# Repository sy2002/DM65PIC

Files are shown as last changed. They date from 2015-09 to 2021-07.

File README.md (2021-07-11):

# Firmware for the DM65PIC
## MEGA65 Computer
DM65PIC_PCBs

MEGA65 is an open-source new and open C65-like computer.
All hardware designs and all software are open-source (LGPL).
Please visit www.mega65.org to learn more about it.

## Quickstart

Click here: [How to flash the firmware on the DM65PIC](bin/README.md)

## DM65PIC Peripheral Interface Controller
The DM65PIC is the peripheral interface controller for the MEGA65 computer.
It is based on the [STM32F4 microcontroller](http://www.st.com/stm32f4).

The purpose of the DM65PIC is to provide an interface to an original
Commodore 65 prototype keyboard or a standard C64 keyboard and to provide
joystick ports. Future versions will also be able to work with the MEGA65
custom keyboard and these keyboards will also be able to be used as standard
USB HID devices e.g. while using emulators. Additionally we will implement the
Commodore 65 user port in future versions.

Here is a foto of some prototype version of our custom PCB:

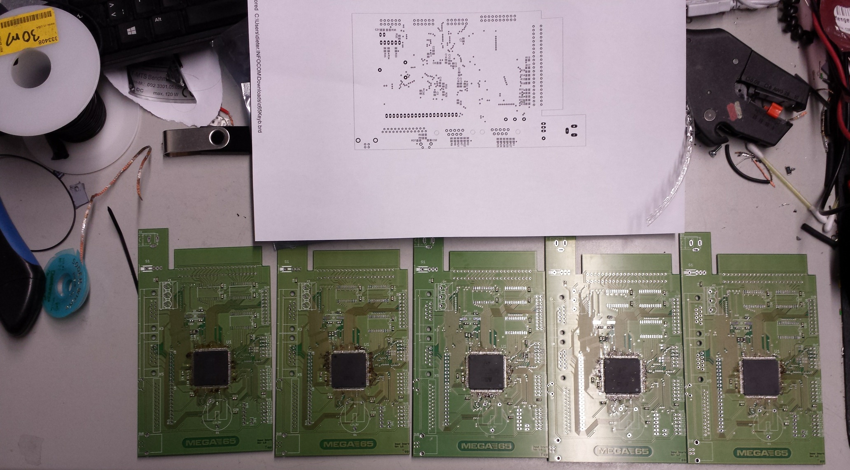
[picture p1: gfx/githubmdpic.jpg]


This GitHub repository is containing the firmware of the DM65PIC.

You can see a combination of a MEGA65 FPGA prototype (based on a Nexys 4 DDR
board), a DMPIC65 prototype and a very first work-in-progress version of the
firmware in conjuncton with a real Commodore 65 prototype keyboard in action
on YouTube: [https://youtu.be/5PpsEw80j3M](https://youtu.be/5PpsEw80j3M).

### Folder structure
```
00-STM32F4xx_STANDARD_PERIPHERAL_DRIVERS  STM32 CMSIS and standard peripheral drivers
00-STM32F429_LIBRARIES                    Tilen Majerle's STM32F4 library
01-DM65PIC                                Firmware for the DM65PIC
bin                                       Firmware binary and how-to-flash documentation
eagle                                     Hardware design for the PCB
```

The actual firmware is located within the file `main.c` in the folder
`01-DM65PIC/01-DM65PIC/User`.

### How to flash
In the folder `bin` you always find the latest binary version of the firmware
as a `.hex` file. There is also the file `bin/README.md` that explains you
how to build a cable and how to flash the DM65PIC firmware using a Windows,
OSX or Linux machine.

### How to build
We used the free version of [Keil uVision5](http://www.keil.com/uvision/).
The free version is code-size constrained (32KB), but as our compiled firmware
(including all the libs) is smaller than 32KB, the free version works fine.

After having installed the Keil IDE, just double click or open the file
`project.uvprojx` in the `01-DM65PIC` folder. As all paths are relative, you
should be able to build without further modifications.

### How the interface works
The DM65PIC is doing a matrix scan on the original Commodore 65 keyboard by
letting current flow through the columns and then find out if a key is pressed
by checking, if the current from the column arrives at a certain row. That
means, we configure all "column pins" of the STM32 microcontroller as outputs
(no pullup/pulldown resistor) and all "row pins" as inputs (pulldown
resistor).

The following diagram is the basis for the matrix scan. It is taken from
Commodore's original document
[c65manual.txt](http://www.zimmers.net/cbmpics/cbm/c65/c65manual.txt)
([permalink](https://perma.cc/E5R3-MEXA)),
chapter 2.1.2.

```

            +-----+-----+-----+-----+-----+-----+-----+-----+-----+            +-----+
            | C0  | C1  | C2  | C3  | C4  | C5  | C6  | C7  | C8  |            | GND |
            |PIN20|PIN19|PIN18|PIN17|PIN16|PIN15|PIN14|PIN13|PIN-4|            |PIN-1|
            +--+--+--+--+--+--+--+--+--+--+--+--+--+--+--+--+--+--+            +--+--+
               |     |     |     |     |     |     |     |     |                  |
               |     |     |     |     |     |     |     |     |                  |
               V     V     V     V     V     V     V     V     V                  |
+-----+     +-----+-----+-----+-----+-----+-----+-----+-----+-----+               |
| R0  |<----+ INS |  #  |  %  |  '  |  )  |  +  | œ   |  !  | NO  |               |
|PIN12|     | DEL |  3  |  5  |  7  |  9  |     |     |  1  | SCRL|               |
+-----+     +-----+-----+-----+-----+-----+-----+-----+-----+-----+               |
| R1  |<----+ RET |  W  |  R  |  Y  |  I  |  P  |  *  | <-- | TAB |               |
|PIN11|     |     |     |     |     |     |     |     |     |     |               |
+-----+     +-----+-----+-----+-----+-----+-----+-----+-----+-----+               |
| R2  |<----+ HORZ|  A  |  D  |  G  |  J  |  L  |  ]  | CTRL| ALT |               |
|PIN10|     | CRSR|     |     |     |     |     |  ;  |     |     +----------+    |
+-----+     +-----+-----+-----+-----+-----+-----+-----+-----+-----+          |    |
| R3  |<----+ F8  |  $  |  &  |  {  |  0  |  -  | CLR |  "  | HELP|          |    |
|PIN-9|     | F7  |  4  |  6  |  8  |     |     | HOM |  2  |     |          |    |
+-----+     +-----+-----+-----+-----+-----+-----+-----+-----+-----+          |    |
| R4  |<----+ F2  |  Z  |  C  |  B  |  M  |  >  |RIGHT|SPACE| F10 |          |    |
|PIN-8|     | F1  |     |     |     |     |  .  |SHIFT| BAR | F9  |          |    |
+-----+     +-----+-----+-----+-----+-----+-----+-----+-----+-----+          |    |
| R5  |<----+ F4  |  S  |  F  |  H  |  K  |  [  |  =  | C=  | F12 |          |    |
|PIN-7|     | F3  |     |     |     |     |  :  |     |     | F11 |          |    |
+-----+     +-----+-----+-----+-----+-----+-----+-----+-----+-----+          |    |
| R6  |<----+ F6  |  E  |  T  |  U  |  O  |  @  |  ã  |  Q  | F14 |          |    |
|PIN-6|     | F5  |     |     |     |     |     |  ^  |     | F13 |          |    |
+-----+     +-----+-----+-----+-----+-----+-----+-----+-----+-----+          |    |
| R7  |<----+ VERT|LEFT |  X  |  V  |  N  |  <  |  ?  | RUN | ESC +------+   |    |
|PIN-5|     | CRSR|SHIFT|     |     |     |  ,  |  /  | STOP|     +--+   |   |    |
+-----+     +--+--+--+--+-----+-----+-----+-----+--+--+-----+-----+  |   |   |    |
               |     |                             |                 |   |   |    |
               |     |                             |                 |   |   |    |
               |  +--+--+     /      (LOCKING)     |                 |   |   |    |
               |  |SHIFT+----+  +------------------------------------+   |   |    |
               |  | LOCK|                          |                     |   |    |
               |  +-----+                          |                     |   |    |
               |                             +-----+-----+               |   |    |
            +--+--+                          |           |               |   |    |
            |CRSR +------------+-------------+           +---------------+   |    |
            | UP  |        K1 PIN-21         |           |                   |    |
            +--+--+                          |   4066    |                   |    |
               |                             |  DECODER  |                   |    |
            +--+--+                          |           |                   |    |
            |CRSR +------------+-------------+           +-------------------+    |
            |LEFT |        K2 PIN-22         |           |                        |
            +-----+                          +-----------+                        |
                                                                                  |
+-----+           +-----+     /                                                   |
| NMI | <---------+RESTR+----+  +-------------------------------------------------+
|PIN-3|           |     |                                                         |
+-----+           +-----+                                                         |
                                                                                  |
                                                                                  |
+-----+           +-----+     /      (LOCKING)                                    |
| R8  | <---------+CAPS +----+  +-------------------------------------------------+
|PIN-2|           |LOCK |
+-----+           +-----+

Keyboard Notes:

1. The  64 keys under C0 through C7 occupy the same matrix position as
   in the C/64,  as does the RESTORE key.  Including SHIFT-LOCK, there
   are 66 such keys.

2. The  extended  keyboard consists of the 8 keys under the C8 output.
   Counting the CAPS-LOCK key, there are 9 new keys. The C/64 does not
   scan these keys.

3. The new CURSOR LEFT and CURSOR UP keys simulate a CURSOR plus RIGHT
   SHIFT key combination.

4. The  keyboard mechanism will be mechanically similar to that of the
   C128.
```

While scanning the matrix, the DM65PIC firmware stores the status of each
single key in an array, that is then transmitted to the MEGA65 FPGA using
the Nexys 4 DDR's General Purpose IO (GPIO) port "JB".

The protocol between the DM65PIC and the FPGA works like this: Cyclically,
128-bit are transmitted as 32 (4-bit) nibbles. Each nibble represents 4 bit
within the above-mentioned matrix. Nibble #0 represents the keys INS/DEL,
RET, HORZ/CRSR, F8/F7. Nibble #1 represents F2/F1, F4/F3, F6/F5, VERT/CRSR.
And so on. Here is the full description of the data sequence:

```
nbls #0 - #17:   keyboard bits corresponding to the 9 columns of keys (see above)
nbl #18:         joystick 1: bit0=up, bit1=down, bit2=left, bit3=right
nbl #19:         bit0=joy1 fire, bit2=capslock key status, bit3=restore key status
nbl #20:         joystick 2: bit0=up, bit1=down, bit2=left, bit3=right
nbl #21:         bit0=joy2 fire, bit3=reset momentary-action switch status
nbl #22 onwards: expansion port connector
```

The nibbles are transmitted by setting below-mentioned "bit0" .. "bit3" pins
of the "JB" port and then clocking pin "JB1". For synchronizing the
transmission, the "start of sequence" pin "JB2" is used as soon as a new
128-bit package starts.

The FPGA is also able to communicate back to the DM65PIC, i.e. for transmitting
the LED status; but this is not supported, yet in the current version of the
firmware.

Here is the pin layout for the FPGA's "JB" port:

```
JB1  = PG8:  clock; data must be valid before rising edge
JB2  = PG9:  start of sequence, set to 1 on first nibble of a new 128bit sequence
JB3  = PG10: bit0 of output data nibble
JB4  = PG11: bit1 of output data nibble
JB7  = PG12: bit2 of output data nibble
JB8  = PG13: bit3 of output data nibble
JB9  = PG14: bit 0 of input bit pair
JB10 = PG15: bit 1 of input bit pair
```

### Credits
* [Paul Gardner-Stephen](http://c65gs.blogspot.de): MEGA65 main developer
* [Deft](http://www.m-e-g-a.org/de/mega/profile): chief MEGA65 officer
* doubleflash: DM65PIC hardware design
* [sy2002](http://www.sy2002.de): DM65PIC firmware in this GitHub repository

Special thanks go to [Tilen Majerle](https://github.com/MaJerle) for
supporting sy2002 in learning how to work with the STM32 toolchain and of
course for creating the awesome [STM32F4 library](https://stm32f4-discovery.net)
that we heavily used for creating the DM65PIC firmware.

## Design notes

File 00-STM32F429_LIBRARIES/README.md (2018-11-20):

# Libraries

Each library listed here is described at
https://stm32f4-discovery.net/

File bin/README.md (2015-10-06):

How to flash the firmware on the DM65PIC
========================================

Get the latest firmware and instructions here:

https://github.com/sy2002/DM65PIC/tree/master/bin

What you need
-------------

1. You need to have a ST-LINK/V2 (or compatible) device connected to any
   USB port of your PC, Mac or Linux device.

2. You need a cable that maps the 20-pin connector of the ST-LINK device
   to the 6-pin connector on the DM65PIC board. (Depending on the type of your
   ST-LINK device, you might only need to connect 4 or 5 of the 6 pins on the
   DM65PIC.)

3. You need either the original STLINK tool, if you're using Windows or
   the Open Source tool OpenOCD, if you're using OSX or Linux.

Cables and Devices
------------------

There a lot of ST-LINK/V2 compatible devices out there. We tried the original
from ST as well as cheap Chines clones. It works, no matter what (compatible)
device you are using, as long as you have the right pin-mapping on the cable.

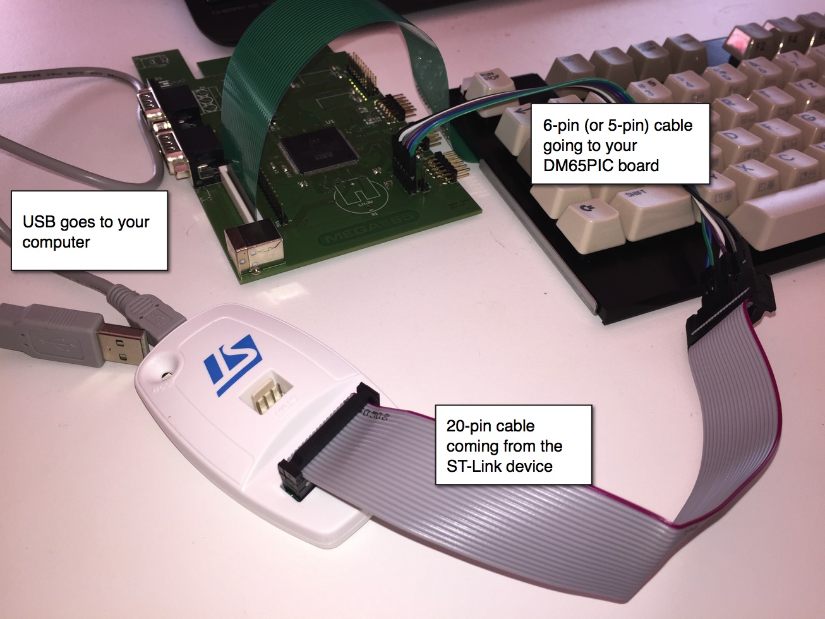
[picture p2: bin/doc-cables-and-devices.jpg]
Cables-and-Devices

   
As you can see on the image above, the programmer is connected via USB to your
host machine. Instructions for Windows, Mac and Linux of about the software
side of things are below.

Let's focus on the cable first: Most ST-LINK devices come with some kind of
a 20-pin connector. We don't need all of these 20 pins to program the DM65PIC,
but just 4 or 5 of them are really essential. Optionally, we can connect
pin 6, which then can be used to display debug- and trace-output on a console.

The original ST-LINK device needs 5 pins as it needs the +3.3 volt line. In
contrast to this, some Chinese clones do not need the +3.3 volt line, so that
4 pins are sufficient for these devices (pins 1 and 6 are omitted).

The following picture is showing you, where to find the 6-pin connector on the
DM65PIC board. You are counting the 6 pins from top to bottom:

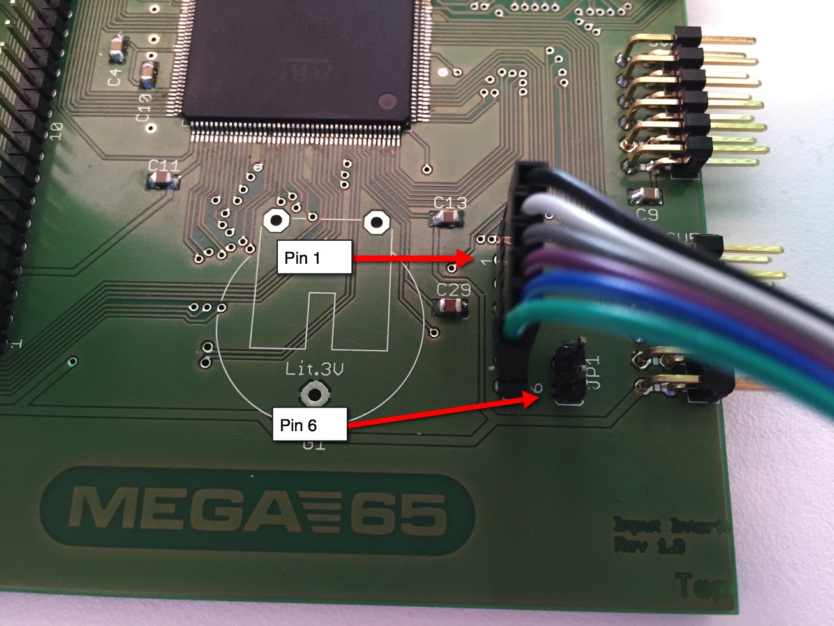
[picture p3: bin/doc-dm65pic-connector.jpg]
DM65PIC-Connector


The meaning of the 6 pins is the following:

```
1 +3.3 volt  (The programmer uses this to detect the device)
2 SWCLK      (ST Wire Bus Clock)
3 GND
4 SWDIO      (ST Input/Output)
5 NRST       (Reset Wire)
6 SWDTO      (Trace Output, this is optional and not needed for flashing)
```

To build the mapping from the 20-pin ST-LINK cable to the 6-pin DM65PIC
connector, you need standard jumper wires male-female or female-female
(depending on how your ST-LINK cable or adapter looks). Some of the ST-LINK
devices are already coming with a set of jumper wires, but you can also
easily get them on eBay or Amazon: Just enter something like
`jumper wire male female` or `breadboard cable male female` into the
search bar. It looks like this:

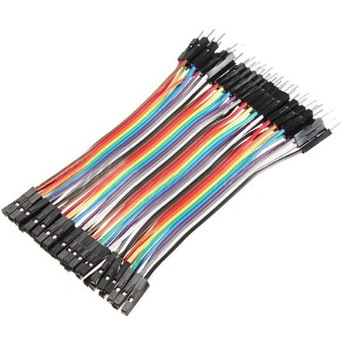
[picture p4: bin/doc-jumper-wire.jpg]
Jumper-Wire-Male-Female


"Mapping" as mentioned above now means: Make sure, that the 3.3 volt pin of
your programming device maps to the 3.3 volt pin of the DM65PIC, which is
pin 1. Make sure, that the SWCLK pin of the programming device maps to the
SWCLK pin of the DM65PIc, which is pin 2. And so on. You can find out the
mapping by having a look in the reference manual of your device.

If you are using an original device from ST or a device with compatible
connectors, then the mapping is as follows:

```
   DM65PIC       ST-LINK
      *1   --->     1
       2   --->     9
       3   --->     6
       4   --->     7
       5   --->    15
     **6   --->    13

(*)  not needed when using some Chinese clones
(**) optional connection, only used for tracing/debugging (ARM Semihosting)
```

Make sure, that you are counting the pins on the ST-LINK connector in the
right way as shown in the following image:

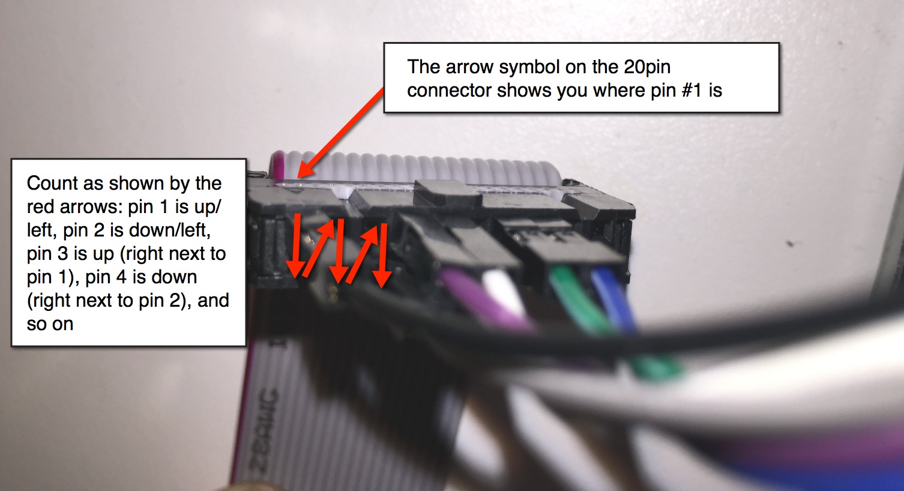
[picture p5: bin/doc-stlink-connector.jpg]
how-to-count


Now you are ready to program / flash your DM65PIC board as described in the
following sections.

Windows
-------

1. Go to www.st.com

2. Enter   STSW-LINK004   in the search box on the top right

3. Click on the first search result

4. Download, install and start the software

5. Choose "Connect" from the "Target" menu. If this is not working,
   then your STLINK-to-DM65PIC cable is wrong and/or DM65PIC is not powered.

6. The "Connect" takes about 5 seconds

7. Choose "Program & Verify" from the "Target" menu

8. Choose the `dm65pic-firmware-rev3.hex` file

9. Select "Verify after programming" and make sure that "Reset after
   programming" is checked.

10. Press "Start".

The firmware is now persistently flashed and will start as soon
as the DM65PIC is powered on.

Mac OSX or Linux
----------------

1. Get the tool OpenOCD from here http://openocd.org

2. For OSX users: If you use homebrew (recommended! http://brew.sh) then
   installing OpenOCD is very easy. Just open a terminal and enter:

   `brew install openocd`

3. Copy the file `dm65pic.cfg` from this repository to some folder on your
   computer, open a terminal and go to that folder where you copied
   `dm65pic.cfg`.

4. Enter:

   `openocd --file dm65pic.cfg`

   If any error occurs, then your cable STLINK-to-DM65PIC is wrong and/or
   DM65PIC is not powered.

5. Executing (4) creates a local telnet server on port 4444, so open another
   terminal window and enter

   `telnet localhost 4444`

6. Enter

   `halt`

7. Enter

   `flash write_image erase <fullpath-to-the-hex-file>`

   In the <fullpath-to-the-hex-file> no things like "~" are allowed.
   Use really the full path starting from the root folder.

8. If an error occurs,  enter:

    ```
    halt
    reset
    halt
    ```

9. And then try (7) again.

10. If it says something like "wrote xyz bytes from file abc" then enter

   `reset`

   (reset starts the firmware)

11. Enter:

    `exit`

12. You can now close all terminal windows, including the OpenOCD server

The firmware is now persistently flashed and will start as soon
as the DM65PIC is powered on.

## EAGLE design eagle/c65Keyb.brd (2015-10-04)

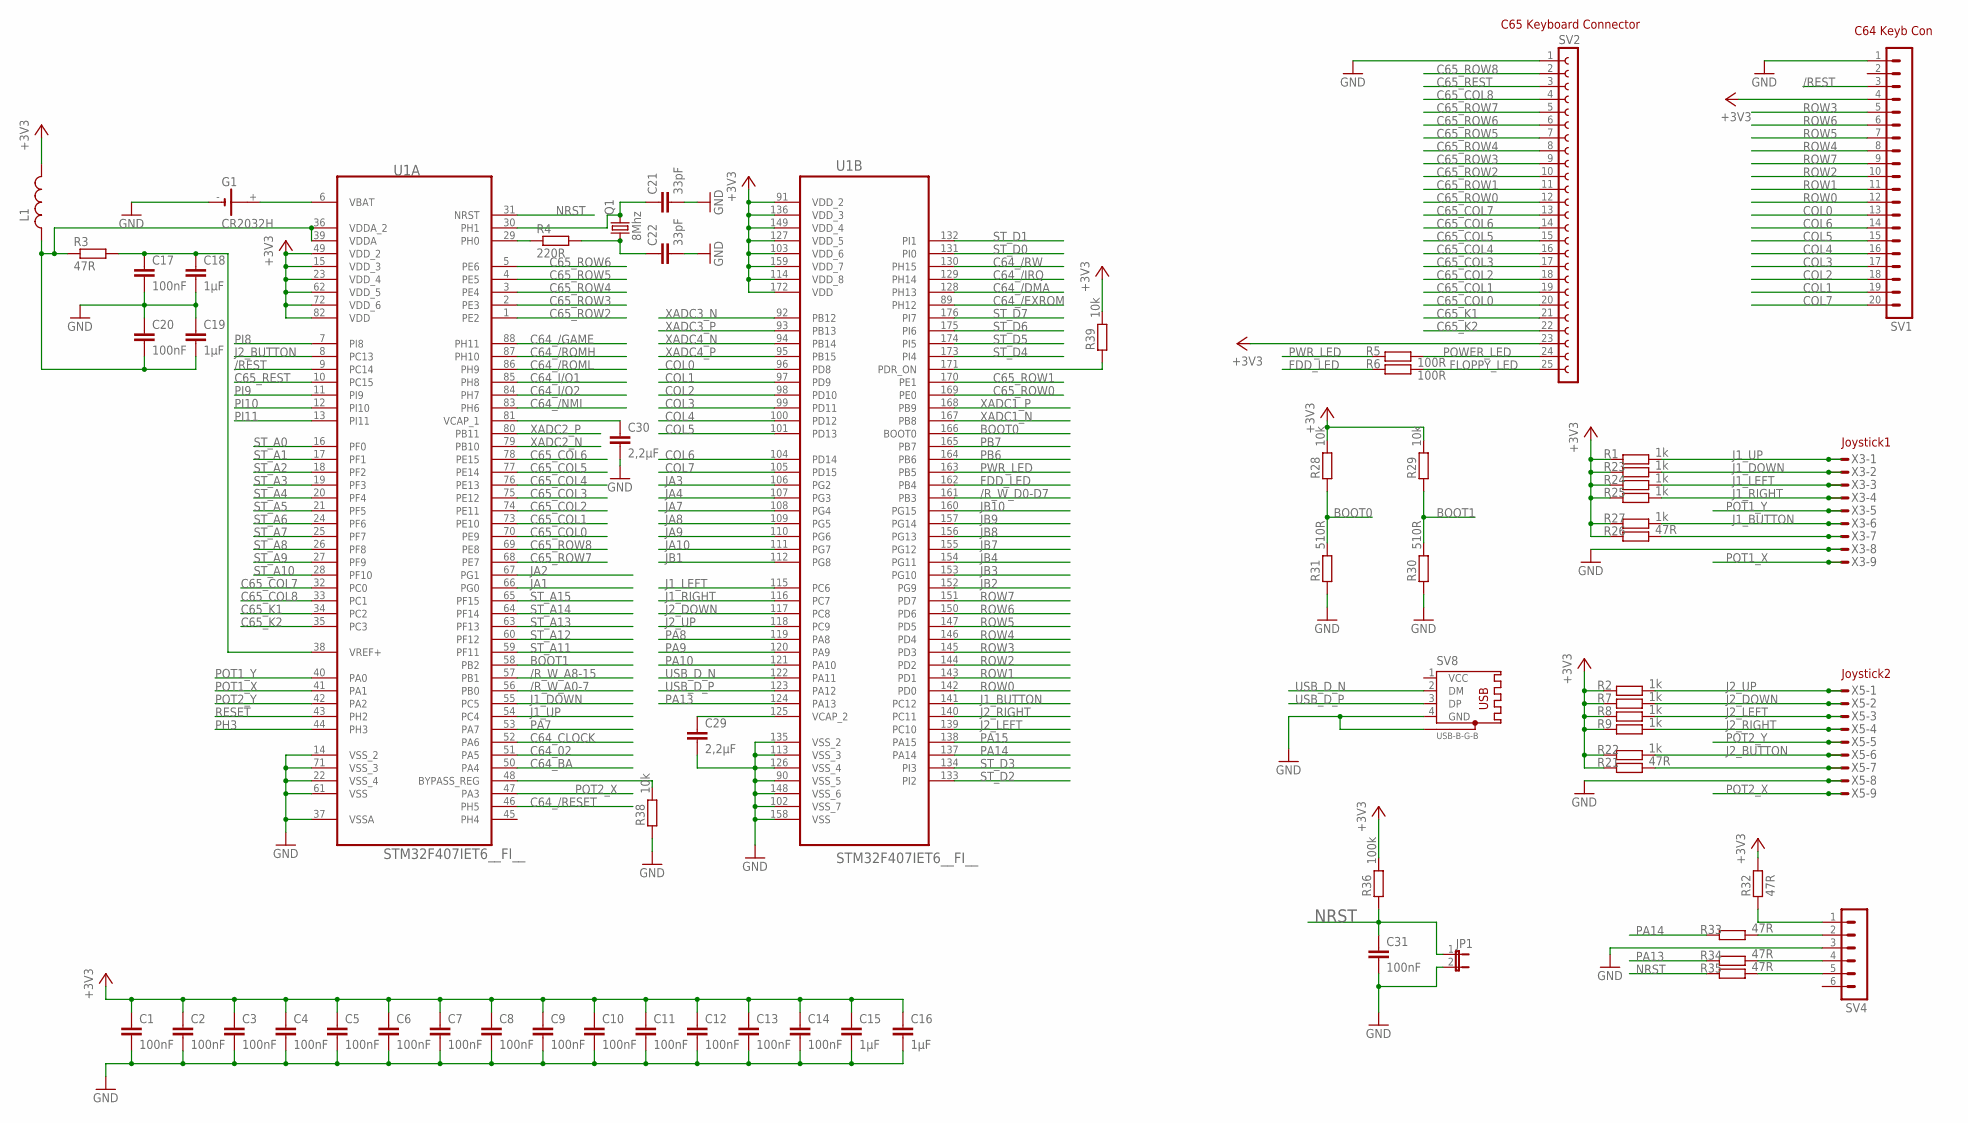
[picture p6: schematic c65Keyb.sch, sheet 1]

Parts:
C1, C2, C3, C4, C5, C6, C7, C8, C9, C10, C11, C12, C13, C14, C17, C20, C31: 100nF; C0805
C15, C16, C18, C19: 1µF; C0805
C21, C22: 33pF; C0805
C29, C30: 2,2µF; C0805
G1: CR2032H
JP1: JP1E; JP1
L1: L-0805A; SMD0805-ALT
Q1: 8Mhz; HC49UP
R1, R2, R7, R8, R9, R22, R23, R24, R25, R27: 1k; R0805
R3, R21, R26, R32, R33, R34, R35: 47R; R0805
R4: 220R; R0805
R5, R6: 100R; R0805
R28, R29, R38, R39: 10k; R0805
R30, R31: 510R; R0805
R36: 100k; R0805
SV1: MA20-1
SV2: C65_MOLEX_KEYB
SV4: MA06-1
SV8: USB-B-G-B; USB-B-THG-01
U1: STM32F407IET6__FI__; QFP176
X3, X5: M09-182S; 182-009-MALE

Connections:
+3V3: C1.1, C2.1, C3.1, C4.1, C5.1, C6.1, C7.1, C8.1, C9.1, C10.1, C11.1, C12.1, C13.1, C14.1, C15.1, C16.1, L1.2, R1.1, R2.1, R7.1, R8.1, R9.1, R21.1, R22.1, R23.1, R24.1, R25.1, R26.1, R27.1, R28.2, R29.2, R32.2, R36.2, R39.2, SV1.4, SV2.23, U1.15 (VDD_3), U1.23 (VDD_4), U1.49 (VDD_2), U1.62 (VDD_5), U1.72 (VDD_6), U1.82 (VDD), U1.91 (VDD_2), U1.103 (VDD_6), U1.114 (VDD_8), U1.127 (VDD_5), U1.136 (VDD_3), U1.149 (VDD_4), U1.159 (VDD_7), U1.172 (VDD); also elsewhere on the board
/REST: SV1.3, U1.9 (PC14)
/R_W_A0-7: U1.56 (PB0); also elsewhere on the board
/R_W_A8-15: U1.57 (PB1); also elsewhere on the board
/R_W_D0-D7: U1.161 (PB3); also elsewhere on the board
BOOT0: R28.1, R31.2, U1.166 (BOOT0)
BOOT1: R29.1, R30.2, U1.58 (PB2)
C64_02: U1.51 (PA5); also elsewhere on the board
C64_/DMA: U1.128 (PH13); also elsewhere on the board
C64_/EXROM: U1.89 (PH12); also elsewhere on the board
C64_/GAME: U1.88 (PH11); also elsewhere on the board
C64_/IRQ: U1.129 (PH14); also elsewhere on the board
C64_/NMI: U1.83 (PH6); also elsewhere on the board
C64_/RESET: U1.46 (PH5); also elsewhere on the board
C64_/ROMH: U1.87 (PH10); also elsewhere on the board
C64_/ROML: U1.86 (PH9); also elsewhere on the board
C64_/RW: U1.130 (PH15); also elsewhere on the board
C64_BA: U1.50 (PA4); also elsewhere on the board
C64_CLOCK: U1.52 (PA6); also elsewhere on the board
C64_I/O1: U1.85 (PH8); also elsewhere on the board
C64_I/O2: U1.84 (PH7); also elsewhere on the board
C65_COL0: SV2.20, U1.70 (PE9)
C65_COL1: SV2.19, U1.73 (PE10)
C65_COL2: SV2.18, U1.74 (PE11)
C65_COL3: SV2.17, U1.75 (PE12)
C65_COL4: SV2.16, U1.76 (PE13)
C65_COL5: SV2.15, U1.77 (PE14)
C65_COL6: SV2.14, U1.78 (PE15)
C65_COL7: SV2.13, U1.32 (PC0)
C65_COL8: SV2.4, U1.33 (PC1)
C65_K1: SV2.21, U1.34 (PC2)
C65_K2: SV2.22, U1.35 (PC3)
C65_REST: SV2.3, U1.10 (PC15)
C65_ROW0: SV2.12, U1.169 (PE0)
C65_ROW1: SV2.11, U1.170 (PE1)
C65_ROW2: SV2.10, U1.1 (PE2)
C65_ROW3: SV2.9, U1.2 (PE3)
C65_ROW4: SV2.8, U1.3 (PE4)
C65_ROW5: SV2.7, U1.4 (PE5)
C65_ROW6: SV2.6, U1.5 (PE6)
C65_ROW7: SV2.5, U1.68 (PE7)
C65_ROW8: SV2.2, U1.69 (PE8)
COL0: SV1.13, U1.96 (PD8)
COL1: SV1.19, U1.97 (PD9)
COL2: SV1.18, U1.98 (PD10)
COL3: SV1.17, U1.99 (PD11)
COL4: SV1.16, U1.100 (PD12)
COL5: SV1.15, U1.101 (PD13)
COL6: SV1.14, U1.104 (PD14)
COL7: SV1.20, U1.105 (PD15)
FDD_LED: R6.1, U1.162 (PB4)
FLOPPY_LED: R6.2, SV2.25
GND: C1.2, C2.2, C3.2, C4.2, C5.2, C6.2, C7.2, C8.2, C9.2, C10.2, C11.2, C12.2, C13.2, C14.2, C15.2, C16.2, C17.2, C18.2, C19.1, C20.1, C21.2, C22.2, C29.2, C30.2, C31.2, G1.-, JP1.2, R30.1, R31.1, R38.1, SV1.1, SV2.1, SV4.3, SV8.4 (GND), SV8.G1, U1.14 (VSS_2), U1.22 (VSS_4), U1.37 (VSSA), U1.61 (VSS), U1.71 (VSS_3), U1.90 (VSS_5), U1.102 (VSS_7), U1.113 (VSS_3), U1.126 (VSS_4), U1.135 (VSS_2), U1.148 (VSS_6), U1.158 (VSS), X3.8, X5.8; also elsewhere on the board
J1_BUTTON: R27.2, U1.141 (PC12), X3.6
J1_DOWN: R23.2, U1.55 (PC5), X3.2
J1_LEFT: R24.2, U1.115 (PC6), X3.3
J1_RIGHT: R25.2, U1.116 (PC7), X3.4
J1_UP: R1.2, U1.54 (PC4), X3.1
J2_BUTTON: R22.2, U1.8 (PC13), X5.6
J2_DOWN: R7.2, U1.117 (PC8), X5.2
J2_LEFT: R8.2, U1.139 (PC10), X5.3
J2_RIGHT: R9.2, U1.140 (PC11), X5.4
J2_UP: R2.2, U1.118 (PC9), X5.1
JA1: U1.66 (PG0); also elsewhere on the board
JA2: U1.67 (PG1); also elsewhere on the board
JA3: U1.106 (PG2); also elsewhere on the board
JA4: U1.107 (PG3); also elsewhere on the board
JA7: U1.108 (PG4); also elsewhere on the board
JA8: U1.109 (PG5); also elsewhere on the board
JA9: U1.110 (PG6); also elsewhere on the board
JA10: U1.111 (PG7); also elsewhere on the board
JB1: U1.112 (PG8); also elsewhere on the board
JB2: U1.152 (PG9); also elsewhere on the board
JB3: U1.153 (PG10); also elsewhere on the board
JB4: U1.154 (PG11); also elsewhere on the board
JB7: U1.155 (PG12); also elsewhere on the board
JB8: U1.156 (PG13); also elsewhere on the board
JB9: U1.157 (PG14); also elsewhere on the board
JB10: U1.160 (PG15); also elsewhere on the board
unnamed: G1.+, U1.6 (VBAT)
unnamed: R4.1, U1.29 (PH0)
unnamed: C17.1, C18.1, R3.2, U1.38 (VREF+)
unnamed: R21.2, X5.7
unnamed: C30.1, U1.81 (VCAP_1)
unnamed: C29.1, U1.125 (VCAP_2)
unnamed: R32.1, SV4.1
unnamed: R33.2, SV4.2
unnamed: R34.2, SV4.4
unnamed: R26.2, X3.7
unnamed: R35.2, SV4.5
unnamed: R38.2, U1.48 (BYPASS_REG)
unnamed: C21.1, Q1.2, U1.30 (PH1)
unnamed: C22.1, Q1.1, R4.2
unnamed: R39.1, U1.171 (PDR_ON)
unnamed: C19.2, C20.2, L1.1, R3.1, U1.36 (VDDA_2), U1.39 (VDDA)
NRST: C31.1, JP1.1, R35.1, R36.1, U1.31 (NRST)
PA7: U1.53 (PA7); also elsewhere on the board
PA8: U1.119 (PA8); also elsewhere on the board
PA9: U1.120 (PA9); also elsewhere on the board
PA10: U1.121 (PA10); also elsewhere on the board
PA13: R34.1, U1.124 (PA13)
PA14: R33.1, U1.137 (PA14)
PA15: U1.138 (PA15); also elsewhere on the board
PB6: U1.164 (PB6); also elsewhere on the board
PB7: U1.165 (PB7); also elsewhere on the board
PH3: U1.44 (PH3); also elsewhere on the board
PI8: U1.7 (PI8); also elsewhere on the board
PI9: U1.11 (PI9); also elsewhere on the board
PI10: U1.12 (PI10); also elsewhere on the board
PI11: U1.13 (PI11); also elsewhere on the board
POT1_X: U1.41 (PA1), X3.9
POT1_Y: U1.40 (PA0), X3.5
POT2_X: U1.47 (PA3), X5.9
POT2_Y: U1.42 (PA2), X5.5
POWER_LED: R5.2, SV2.24
PWR_LED: R5.1, U1.163 (PB5)
RESET: U1.43 (PH2); also elsewhere on the board
ROW0: SV1.12, U1.142 (PD0)
ROW1: SV1.11, U1.143 (PD1)
ROW2: SV1.10, U1.144 (PD2)
ROW3: SV1.5, U1.145 (PD3)
ROW4: SV1.8, U1.146 (PD4)
ROW5: SV1.7, U1.147 (PD5)
ROW6: SV1.6, U1.150 (PD6)
ROW7: SV1.9, U1.151 (PD7)
ST_A0: U1.16 (PF0); also elsewhere on the board
ST_A1: U1.17 (PF1); also elsewhere on the board
ST_A2: U1.18 (PF2); also elsewhere on the board
ST_A3: U1.19 (PF3); also elsewhere on the board
ST_A4: U1.20 (PF4); also elsewhere on the board
ST_A5: U1.21 (PF5); also elsewhere on the board
ST_A6: U1.24 (PF6); also elsewhere on the board
ST_A7: U1.25 (PF7); also elsewhere on the board
ST_A8: U1.26 (PF8); also elsewhere on the board
ST_A9: U1.27 (PF9); also elsewhere on the board
ST_A10: U1.28 (PF10); also elsewhere on the board
ST_A11: U1.59 (PF11); also elsewhere on the board
ST_A12: U1.60 (PF12); also elsewhere on the board
ST_A13: U1.63 (PF13); also elsewhere on the board
ST_A14: U1.64 (PF14); also elsewhere on the board
ST_A15: U1.65 (PF15); also elsewhere on the board
ST_D0: U1.131 (PI0); also elsewhere on the board
ST_D1: U1.132 (PI1); also elsewhere on the board
ST_D2: U1.133 (PI2); also elsewhere on the board
ST_D3: U1.134 (PI3); also elsewhere on the board
ST_D4: U1.173 (PI4); also elsewhere on the board
ST_D5: U1.174 (PI5); also elsewhere on the board
ST_D6: U1.175 (PI6); also elsewhere on the board
ST_D7: U1.176 (PI7); also elsewhere on the board
USB_D_N: SV8.2 (DM), U1.122 (PA11)
USB_D_P: SV8.3 (DP), U1.123 (PA12)
XADC1_N: U1.167 (PB8); also elsewhere on the board
XADC1_P: U1.168 (PB9); also elsewhere on the board
XADC2_N: U1.79 (PB10); also elsewhere on the board
XADC2_P: U1.80 (PB11); also elsewhere on the board
XADC3_N: U1.92 (PB12); also elsewhere on the board
XADC3_P: U1.93 (PB13); also elsewhere on the board
XADC4_N: U1.94 (PB14); also elsewhere on the board
XADC4_P: U1.95 (PB15); also elsewhere on the board

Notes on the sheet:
C64 Keyb Con
Joystick1
Joystick2
C65 Keyboard Connector

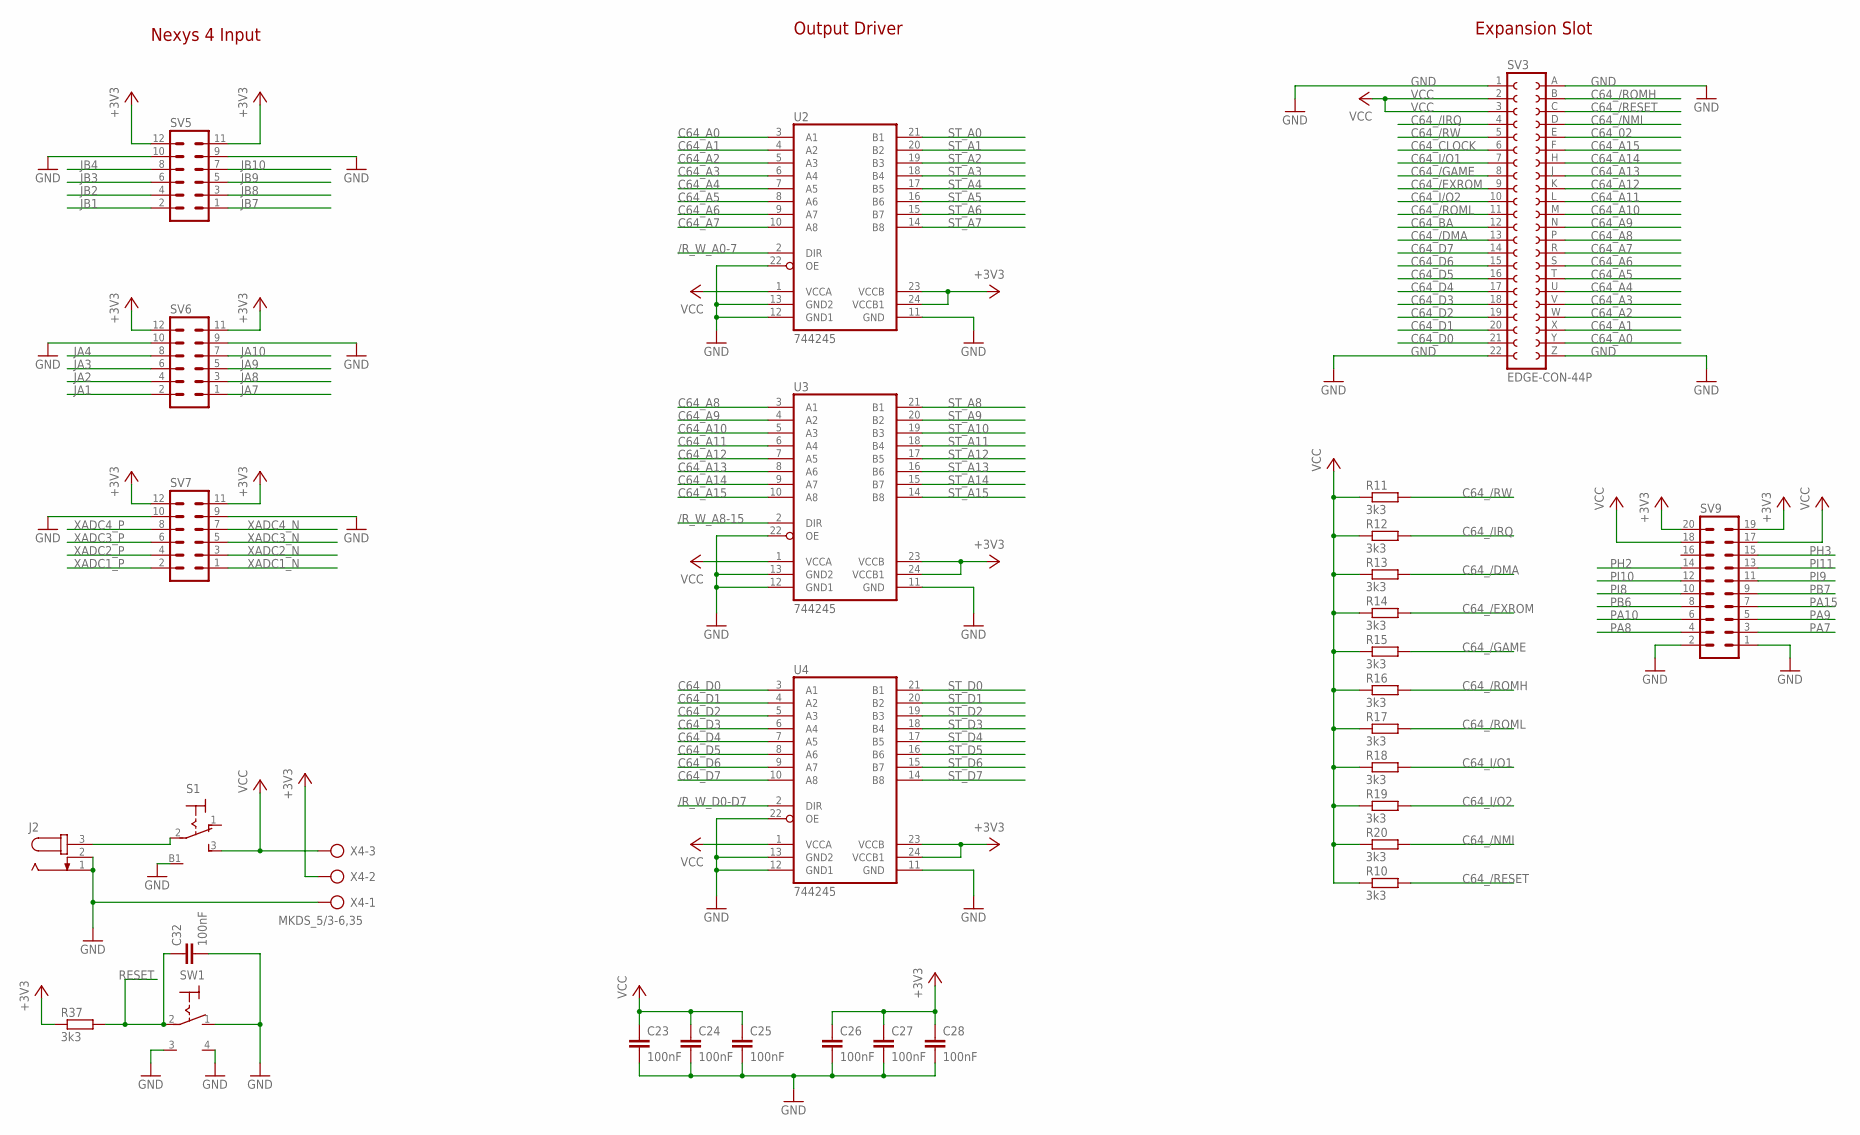
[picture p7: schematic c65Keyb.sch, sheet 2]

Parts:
C23, C24, C25, C26, C27, C28, C32: 100nF; C0805
J2: JACK-PLUG1; SPC4078
R10, R11, R12, R13, R14, R15, R16, R17, R18, R19, R20, R37: 3k3; R0805
S1: LPV-1
SV3: EDGE-CON-44P; EDGE-CON-44
SV5, SV6, SV7: MA06-2W
SV9: MA10-2
SW1: TASTER; MICRO_SWITCH
U2, U3, U4: 744245; SO24L
X4: MKDS_5/3-6,35; MKDS_5/3-635

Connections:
+3V3: C26.1, C27.1, C28.1, R37.1, SV5.11, SV5.12, SV6.11, SV6.12, SV7.11, SV7.12, SV9.19, SV9.20, U2.23 (VCCB), U2.24 (VCCB1), U3.23 (VCCB), U3.24 (VCCB1), U4.23 (VCCB), U4.24 (VCCB1), X4.2; also elsewhere on the board
/R_W_A0-7: U2.2 (DIR); also elsewhere on the board
/R_W_A8-15: U3.2 (DIR); also elsewhere on the board
/R_W_D0-D7: U4.2 (DIR); also elsewhere on the board
C64_02: SV3.E; also elsewhere on the board
C64_/DMA: R13.2, SV3.13; also elsewhere on the board
C64_/EXROM: R14.2, SV3.9; also elsewhere on the board
C64_/GAME: R15.2, SV3.8; also elsewhere on the board
C64_/IRQ: R12.2, SV3.4; also elsewhere on the board
C64_/NMI: R20.2, SV3.D; also elsewhere on the board
C64_/RESET: R10.2, SV3.C; also elsewhere on the board
C64_/ROMH: R16.2, SV3.B; also elsewhere on the board
C64_/ROML: R17.2, SV3.11; also elsewhere on the board
C64_/RW: R11.2, SV3.5; also elsewhere on the board
C64_A0: SV3.Y, U2.3 (A1)
C64_A1: SV3.X, U2.4 (A2)
C64_A2: SV3.W, U2.5 (A3)
C64_A3: SV3.V, U2.6 (A4)
C64_A4: SV3.U, U2.7 (A5)
C64_A5: SV3.T, U2.8 (A6)
C64_A6: SV3.S, U2.9 (A7)
C64_A7: SV3.R, U2.10 (A8)
C64_A8: SV3.P, U3.3 (A1)
C64_A9: SV3.N, U3.4 (A2)
C64_A10: SV3.M, U3.5 (A3)
C64_A11: SV3.L, U3.6 (A4)
C64_A12: SV3.K, U3.7 (A5)
C64_A13: SV3.J, U3.8 (A6)
C64_A14: SV3.H, U3.9 (A7)
C64_A15: SV3.F, U3.10 (A8)
C64_BA: SV3.12; also elsewhere on the board
C64_CLOCK: SV3.6; also elsewhere on the board
C64_D0: SV3.21, U4.3 (A1)
C64_D1: SV3.20, U4.4 (A2)
C64_D2: SV3.19, U4.5 (A3)
C64_D3: SV3.18, U4.6 (A4)
C64_D4: SV3.17, U4.7 (A5)
C64_D5: SV3.16, U4.8 (A6)
C64_D6: SV3.15, U4.9 (A7)
C64_D7: SV3.14, U4.10 (A8)
C64_I/O1: R18.2, SV3.7; also elsewhere on the board
C64_I/O2: R19.2, SV3.10; also elsewhere on the board
GND: C23.2, C24.2, C25.2, C26.2, C27.2, C28.2, C32.2, J2.1, J2.2, S1.B1 (B), SV3.1, SV3.22, SV3.A, SV3.Z, SV5.9, SV5.10, SV6.9, SV6.10, SV7.9, SV7.10, SV9.1, SV9.2, SW1.1 (O), SW1.3 (B), SW1.4 (B1), U2.11 (GND), U2.12 (GND1), U2.13 (GND2), U2.22 (OE), U3.11 (GND), U3.12 (GND1), U3.13 (GND2), U3.22 (OE), U4.11 (GND), U4.12 (GND1), U4.13 (GND2), U4.22 (OE), X4.1; also elsewhere on the board
JA1: SV6.2; also elsewhere on the board
JA2: SV6.4; also elsewhere on the board
JA3: SV6.6; also elsewhere on the board
JA4: SV6.8; also elsewhere on the board
JA7: SV6.1; also elsewhere on the board
JA8: SV6.3; also elsewhere on the board
JA9: SV6.5; also elsewhere on the board
JA10: SV6.7; also elsewhere on the board
JB1: SV5.2; also elsewhere on the board
JB2: SV5.4; also elsewhere on the board
JB3: SV5.6; also elsewhere on the board
JB4: SV5.8; also elsewhere on the board
JB7: SV5.1; also elsewhere on the board
JB8: SV5.3; also elsewhere on the board
JB9: SV5.5; also elsewhere on the board
JB10: SV5.7; also elsewhere on the board
unnamed: J2.3, S1.2
PA7: SV9.3; also elsewhere on the board
PA8: SV9.4; also elsewhere on the board
PA9: SV9.5; also elsewhere on the board
PA10: SV9.6; also elsewhere on the board
PA15: SV9.7; also elsewhere on the board
PB6: SV9.8; also elsewhere on the board
PB7: SV9.9; also elsewhere on the board
PH2: SV9.14
PH3: SV9.15; also elsewhere on the board
PI8: SV9.10; also elsewhere on the board
PI9: SV9.11; also elsewhere on the board
PI10: SV9.12; also elsewhere on the board
PI11: SV9.13; also elsewhere on the board
RESET: C32.1, R37.2, SW1.2; also elsewhere on the board
ST_A0: U2.21 (B1); also elsewhere on the board
ST_A1: U2.20 (B2); also elsewhere on the board
ST_A2: U2.19 (B3); also elsewhere on the board
ST_A3: U2.18 (B4); also elsewhere on the board
ST_A4: U2.17 (B5); also elsewhere on the board
ST_A5: U2.16 (B6); also elsewhere on the board
ST_A6: U2.15 (B7); also elsewhere on the board
ST_A7: U2.14 (B8); also elsewhere on the board
ST_A8: U3.21 (B1); also elsewhere on the board
ST_A9: U3.20 (B2); also elsewhere on the board
ST_A10: U3.19 (B3); also elsewhere on the board
ST_A11: U3.18 (B4); also elsewhere on the board
ST_A12: U3.17 (B5); also elsewhere on the board
ST_A13: U3.16 (B6); also elsewhere on the board
ST_A14: U3.15 (B7); also elsewhere on the board
ST_A15: U3.14 (B8); also elsewhere on the board
ST_D0: U4.21 (B1); also elsewhere on the board
ST_D1: U4.20 (B2); also elsewhere on the board
ST_D2: U4.19 (B3); also elsewhere on the board
ST_D3: U4.18 (B4); also elsewhere on the board
ST_D4: U4.17 (B5); also elsewhere on the board
ST_D5: U4.16 (B6); also elsewhere on the board
ST_D6: U4.15 (B7); also elsewhere on the board
ST_D7: U4.14 (B8); also elsewhere on the board
VCC: C23.1, C24.1, C25.1, R10.1, R11.1, R12.1, R13.1, R14.1, R15.1, R16.1, R17.1, R18.1, R19.1, R20.1, S1.3 (S), SV3.2, SV3.3, SV9.17, SV9.18, U2.1 (VCCA), U3.1 (VCCA), U4.1 (VCCA), X4.3
XADC1_N: SV7.1; also elsewhere on the board
XADC1_P: SV7.2; also elsewhere on the board
XADC2_N: SV7.3; also elsewhere on the board
XADC2_P: SV7.4; also elsewhere on the board
XADC3_N: SV7.5; also elsewhere on the board
XADC3_P: SV7.6; also elsewhere on the board
XADC4_N: SV7.7; also elsewhere on the board
XADC4_P: SV7.8; also elsewhere on the board

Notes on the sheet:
Expansion Slot
Output Driver
Nexys 4 Input

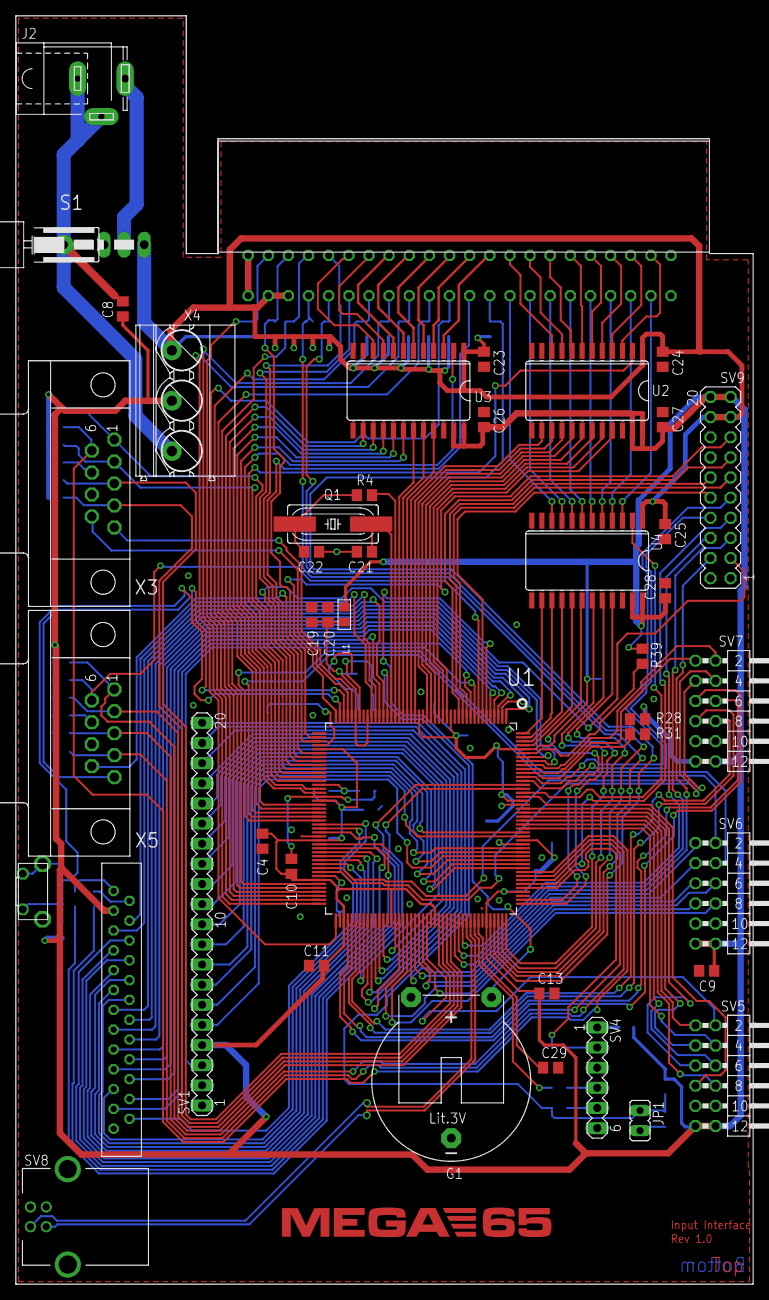
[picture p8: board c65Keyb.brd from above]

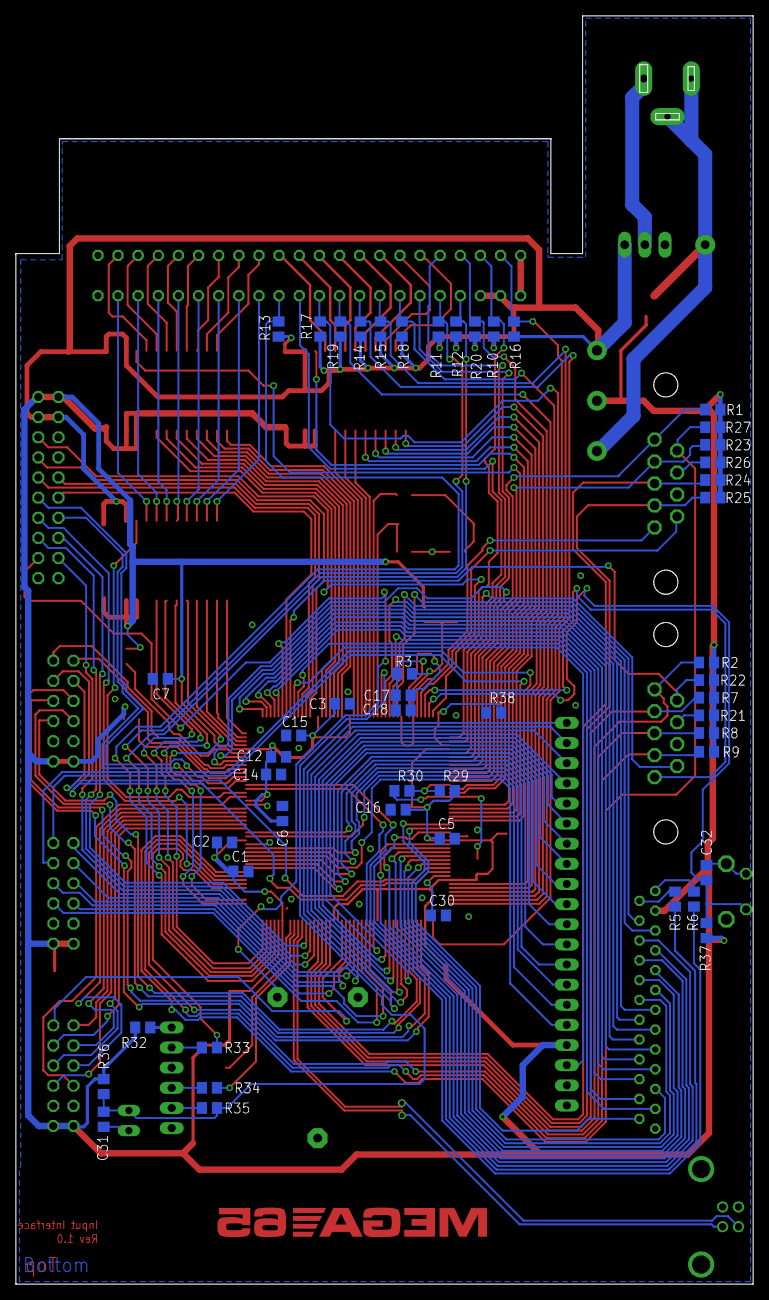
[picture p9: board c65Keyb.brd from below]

Board: 2 copper layers, 93.0 x 160.0 mm, 94 parts (50 on the bottom side), 185 nets.

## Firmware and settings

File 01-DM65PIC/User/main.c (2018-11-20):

/*
 *  FIRMWARE FOR DM65PIC (Dieter's MEGA65 Peripheral Interface Controller)
 *
 *  Keyboard, Joystick and Expansion Port interface for the MEGA65
 *  running on a Nexys 4 DDR FPGA
 * 
 *  done in September 2015 by sy2002 (http://www.sy2002.de)
 *  using Tilen Majerle's STM32F4 libraries (http://stm32f4-discovery.com)
 */

/* Include core modules */
#include "stm32f4xx.h"

/* Include STM32F4 libraries */
#include "defines.h"
#include "tm_stm32f4_swo.h"
#include "tm_stm32f4_gpio.h"
#include "tm_stm32f4_delay.h"

int main(void)
{
    /* complete state of the keyboard split into nibbles according to the FPGA transfer protocol */
    unsigned char nibbles[32] =
    {
        0x00,
        0x00,
        0x00,
        0x00,
        0x00,
        0x00,
        0x00,
        0x00,
        0x00,
        0x00,
        0x00,
        0x00,
        0x00,
        0x00,
        0x00,
        0x00,
        0x00,
        0x00,
        0x00,
        0x00,
        0x00,
        0x00,
        0x00,
        0x00,
        0x00,
        0x00,
        0x00,
        0x00,
        0x00,
        0x00,
        0x00,
        0x00       
    };
    
    
    /* map the pins of the DM65PIC to the columns and rows of the C65 and C64 keyboard
       a very good source of information is chapter 2.1.2 in the following document:

       http://www.zimmers.net/cbmpics/cbm/c65/c65manual.txt 
       
       or use this permalink

       https://perma.cc/E5R3-MEXA
    */
    
    struct GPIO_Mapping
    {
        GPIO_TypeDef* GPIOx;    /* STM32 GPIO port */
        uint16_t GPIO_Pin;      /* pin within the specified GPIO port */
    };
    
    const char Size_ColMapping_C65 = 9;
    struct GPIO_Mapping Columns_C65[Size_ColMapping_C65] =
    {
        GPIOE, GPIO_Pin_9,      /* C0 */
        GPIOE, GPIO_Pin_10,     /* C1 */
        GPIOE, GPIO_Pin_11,     /* C2 */
        GPIOE, GPIO_Pin_12,     /* C3 */
        GPIOE, GPIO_Pin_13,     /* C4 */
        GPIOE, GPIO_Pin_14,     /* C5 */
        GPIOE, GPIO_Pin_15,     /* C6 */
        GPIOC, GPIO_Pin_0,      /* C7 */
        GPIOC, GPIO_Pin_1       /* C8 */
    };
        
    const char Size_RowMapping_C65 = 11;
    struct GPIO_Mapping Rows_C65[Size_RowMapping_C65] =
    {
        GPIOE, GPIO_Pin_0,      /* R0 */
        GPIOE, GPIO_Pin_1,      /* R1 */
        GPIOE, GPIO_Pin_2,      /* R2 */
        GPIOE, GPIO_Pin_3,      /* R3 */
        GPIOE, GPIO_Pin_4,      /* R4 */
        GPIOE, GPIO_Pin_5,      /* R5 */
        GPIOE, GPIO_Pin_6,      /* R6 */
        GPIOE, GPIO_Pin_7,      /* R7 */
        GPIOE, GPIO_Pin_8,      /* R8 is exclusively used for the CAPS LOCK aka ASCII/DIN key */
        GPIOC, GPIO_Pin_2,      /* K1 special "row 9" used for scanning the CURSOR UP key */
        GPIOC, GPIO_Pin_3       /* K2 special "row 10" used for scanning the CURSOR LEFT key */
    };
    
    struct GPIO_Mapping Restore_C65 =
    {
        GPIOC, GPIO_Pin_15      /* RESTORE key */
    };
        
    const char Size_ColMapping_C64 = 8;
    struct GPIO_Mapping Columns_C64[Size_ColMapping_C64] =
    {
        GPIOD, GPIO_Pin_8,      /* C0 */
        GPIOD, GPIO_Pin_9,      /* C1 */
        GPIOD, GPIO_Pin_10,     /* C2 */
        GPIOD, GPIO_Pin_11,     /* C3 */
        GPIOD, GPIO_Pin_12,     /* C4 */
        GPIOD, GPIO_Pin_13,     /* C5 */
        GPIOD, GPIO_Pin_14,     /* C6 */
        GPIOD, GPIO_Pin_15      /* C7 */
    };
        
    const char Size_RowMapping_C64 = 8;
    struct GPIO_Mapping Rows_C64[Size_RowMapping_C64] =
    {
        GPIOD, GPIO_Pin_0,      /* R0 */
        GPIOD, GPIO_Pin_1,      /* R1 */
        GPIOD, GPIO_Pin_2,      /* R2 */
        GPIOD, GPIO_Pin_3,      /* R3 */
        GPIOD, GPIO_Pin_4,      /* R4 */
        GPIOD, GPIO_Pin_5,      /* R5 */
        GPIOD, GPIO_Pin_6,      /* R6 */
        GPIOD, GPIO_Pin_7       /* R7 */        
    };
    
    struct GPIO_Mapping Restore_C64 =
    {
        GPIOC, GPIO_Pin_14      /* RESTORE key */
    };    
            
    /* joystick mapping at the FPGA's JB port: GPIO => nibble-pos and bit-pos
        nbl #18 : joystick 1 : bit0=up, bit1=down, bit2=left, bit3=right
        nbl #19 : bit0=joy1 fire, bit2=capslock key status, bit3=restore key status
        nbl #20 : joystick 2 : bit0=up, bit1=down, bit2=left, bit3=right
        nbl #21 : bit0=joy2 fire, bit3=reset momentary-action switch status
    
       in C65 mode, which is the default, port #1 and #2 are swapped due to the
       way, how the DM65PIC is located in the MEGA65 body housing; this is why
       in below-mentioned table, joystick #1's left is going to nbl #20 instead of #18
    */  
    const char Size_JoyMapping = 10;    
    struct
    {
        GPIO_TypeDef* GPIOx;
        uint16_t GPIO_Pin;
        char nibble_count;
        char bit_count;
    } Joystick[Size_JoyMapping] =
    {
        GPIOC, GPIO_Pin_6,  20, 2,  /* Joystick #1 LEFT */
        GPIOC, GPIO_Pin_7,  20, 3,  /* Joystick #1 RIGHT */
        GPIOC, GPIO_Pin_4,  20, 0,  /* Joystick #1 UP */
        GPIOC, GPIO_Pin_5,  20, 1,  /* Joystick #1 DOWN */
        GPIOC, GPIO_Pin_12, 21, 0,  /* Joystick #1 BUTTON */
        
        GPIOC, GPIO_Pin_10, 18, 2,  /* Joystick #2 LEFT */
        GPIOC, GPIO_Pin_11, 18, 3,  /* Joystick #2 RIGHT */
        GPIOC, GPIO_Pin_9 , 18, 0,  /* Joystick #2 UP */
        GPIOC, GPIO_Pin_8,  18, 1,  /* Joystick #2 DOWN */
        GPIOC, GPIO_Pin_13, 19, 0   /* Joystick #2 BUTTON */
    };
    
    struct GPIO_Mapping LEDs[2] =
    {
        GPIOB, GPIO_Pin_5,          /* Power LED */
        GPIOB, GPIO_Pin_4           /* FDD LED */
    };
    
    const char ledPower = 0;
    const char ledFDD = 1;
        
    /* positions of special keys within the matrix */
    const char COL_CSR = 0;
    const char ROW_CSR_UP = 9;
    const char ROW_CSR_LEFT = 10;
    const char ROW_CAPSLOCK = 8;
    
    /* positions of special keys within the nibbles array */
    const char NIBBLE_CSR_DOWN = 1;
    const char BIT_CSR_DOWN = 3;
    const char NIBBLE_CSR_RIGHT = 0;
    const char BIT_CSR_RIGHT = 2;
    const char NIBBLE_RIGHT_SHIFT = 13;
    const char BIT_RIGHT_SHIFT = 0;
    const char NIBBLE_RESTORE = 19;
    const char BIT_RESTORE = 3;
    const char NIBBLE_CAPSLOCK = 19;
    const char BIT_CAPSLOCK = 2;
    
    int i, col, row, nibble_cnt, bit_cnt;
    int tmp_offs, tmp_nbl, tmp_bit;
        
    char FPGA_IN_PowerLed = 0;
    char FPGA_IN_FDDLed = 0;
    
    /* if ever any key of a C64 keyboard has been pressed, then DM64PIC switches into
       a dedicated C64 mode that swaps back the joystick ports to their "natural" (aka as printed on the PBC)
       order because when the DM65PIC is located in a C64 body housing, the ports are placed correctly */
    char C64_Mode = 0;
            
	/* Initialize System */
	SystemInit();
    TM_DELAY_Init();
	TM_SWO_Init();  

	TM_SWO_Printf("DM64PIC firmware running.\n");
    
    /* The matrix scan goes like this: let current flow through the columns and then find out if a key is pressed
       by checking, if the current from the column arrives at a certain row. That means, we configure
       all columns as outputs (no pullup/pulldown resistor) and all rows as inputs (pulldown resistor)
    */
    for (i = 0; i < Size_ColMapping_C65; i++)
        TM_GPIO_Init(Columns_C65[i].GPIOx, Columns_C65[i].GPIO_Pin, TM_GPIO_Mode_OUT, TM_GPIO_OType_PP, TM_GPIO_PuPd_NOPULL, TM_GPIO_Speed_High);    
    for (i = 0; i < Size_RowMapping_C65; i++)
        TM_GPIO_Init(Rows_C65[i].GPIOx, Rows_C65[i].GPIO_Pin, TM_GPIO_Mode_IN, TM_GPIO_OType_PP, TM_GPIO_PuPd_DOWN, TM_GPIO_Speed_High);
    for (i = 0; i < Size_ColMapping_C64; i++)
        TM_GPIO_Init(Columns_C64[i].GPIOx, Columns_C64[i].GPIO_Pin, TM_GPIO_Mode_OUT, TM_GPIO_OType_PP, TM_GPIO_PuPd_NOPULL, TM_GPIO_Speed_High);    
    for (i = 0; i < Size_RowMapping_C64; i++)
        TM_GPIO_Init(Rows_C64[i].GPIOx, Rows_C64[i].GPIO_Pin, TM_GPIO_Mode_IN, TM_GPIO_OType_PP, TM_GPIO_PuPd_DOWN, TM_GPIO_Speed_High);
        
    /* row 8 is exclusively used for CAPS LOCK (aka ASCII/DIN) and has inverse logic
      (pulled to GND when the key is pressed), so use pullup resistor */
    TM_GPIO_Init(Rows_C65[ROW_CAPSLOCK].GPIOx, Rows_C65[ROW_CAPSLOCK].GPIO_Pin, TM_GPIO_Mode_IN, TM_GPIO_OType_PP, TM_GPIO_PuPd_UP, TM_GPIO_Speed_High);
    
    /* The RESTORE key is pulled to GND when pressed, so we need a pullup resistor */
    TM_GPIO_Init(Restore_C65.GPIOx, Restore_C65.GPIO_Pin, TM_GPIO_Mode_IN, TM_GPIO_OType_PP, TM_GPIO_PuPd_UP, TM_GPIO_Speed_High);
    TM_GPIO_Init(Restore_C64.GPIOx, Restore_C64.GPIO_Pin, TM_GPIO_Mode_IN, TM_GPIO_OType_PP, TM_GPIO_PuPd_UP, TM_GPIO_Speed_High);
        
    /* Joysticks are inverse logic, too, therefore pullup resistors are needed for the inputs */
    for (i = 0; i < Size_JoyMapping; i++)
        TM_GPIO_Init(Joystick[i].GPIOx, Joystick[i].GPIO_Pin, TM_GPIO_Mode_IN, TM_GPIO_OType_PP, TM_GPIO_PuPd_UP, TM_GPIO_Speed_High);
    
    /* Initialze outputs for LEDs */
    TM_GPIO_Init(LEDs[ledPower].GPIOx, LEDs[ledPower].GPIO_Pin, TM_GPIO_Mode_OUT, TM_GPIO_OType_PP, TM_GPIO_PuPd_NOPULL, TM_GPIO_Speed_Low);
    TM_GPIO_Init(LEDs[ledFDD].GPIOx, LEDs[ledFDD].GPIO_Pin, TM_GPIO_Mode_OUT, TM_GPIO_OType_PP, TM_GPIO_PuPd_NOPULL, TM_GPIO_Speed_Low);
    
    /* Initialize outputs for communicating with the FPGA via GPIO port JB for debugging    
        JB1  = PG8: clock; data must be valid before rising edge
        JB2  = PG9: start of sequence, set to 1 when the first nibble of a new 128bit sequence is presented
        JB3  = PG10: bit0 of output data nibble
        JB4  = PG11: bit1 of output data nibble
        JB7  = PG12: bit2 of output data nibble
        JB8  = PG13: bit3 of output data nibble
        JB9  = PG14: bit 0 of input bit pair
        JB10 = PG15: bit 1 of input bit pair
    */
  
    #define P_CLOCK     GPIO_Pin_8
    #define P_START     GPIO_Pin_9
    #define P_OUT_B0    GPIO_Pin_10
    #define P_OUT_B1    GPIO_Pin_11
    #define P_OUT_B2    GPIO_Pin_12
    #define P_OUT_B3    GPIO_Pin_13
    #define P_IN_B0     GPIO_Pin_14
    #define P_IN_B1     GPIO_Pin_15
       
    /* defines for debug port JA
    #define P_CLOCK     GPIO_Pin_0
    #define P_START     GPIO_Pin_1
    #define P_OUT_B0    GPIO_Pin_2
    #define P_OUT_B1    GPIO_Pin_3
    #define P_OUT_B2    GPIO_Pin_4
    #define P_OUT_B3    GPIO_Pin_5
    #define P_IN_B0     GPIO_Pin_6
    #define P_IN_B1     GPIO_Pin_7
    */
        
    /* initialize the pins for the FPGA GPIO communication */
    TM_GPIO_Init(GPIOG, P_CLOCK,  TM_GPIO_Mode_OUT, TM_GPIO_OType_PP, TM_GPIO_PuPd_NOPULL, TM_GPIO_Speed_High);
    TM_GPIO_Init(GPIOG, P_START,  TM_GPIO_Mode_OUT, TM_GPIO_OType_PP, TM_GPIO_PuPd_NOPULL, TM_GPIO_Speed_High);
    TM_GPIO_Init(GPIOG, P_OUT_B0, TM_GPIO_Mode_OUT, TM_GPIO_OType_PP, TM_GPIO_PuPd_NOPULL, TM_GPIO_Speed_High);
    TM_GPIO_Init(GPIOG, P_OUT_B1, TM_GPIO_Mode_OUT, TM_GPIO_OType_PP, TM_GPIO_PuPd_NOPULL, TM_GPIO_Speed_High);
    TM_GPIO_Init(GPIOG, P_OUT_B2, TM_GPIO_Mode_OUT, TM_GPIO_OType_PP, TM_GPIO_PuPd_NOPULL, TM_GPIO_Speed_High);
    TM_GPIO_Init(GPIOG, P_OUT_B3, TM_GPIO_Mode_OUT, TM_GPIO_OType_PP, TM_GPIO_PuPd_NOPULL, TM_GPIO_Speed_High);    
    TM_GPIO_Init(GPIOG, P_IN_B0,  TM_GPIO_Mode_IN,  TM_GPIO_OType_PP, TM_GPIO_PuPd_DOWN,   TM_GPIO_Speed_High);
    TM_GPIO_Init(GPIOG, P_IN_B1,  TM_GPIO_Mode_IN,  TM_GPIO_OType_PP, TM_GPIO_PuPd_DOWN,   TM_GPIO_Speed_High);

    /* convenience defines for a better readability */
    #define FPGA_OUT(__pin, __value) TM_GPIO_SetPinValue(GPIOG, __pin, __value)
    #define FPGA_IN(__pin) TM_GPIO_GetInputPinValue(GPIOG, __pin)
    #define DM_SET_BIT(__nibblepos, __bitpos) nibbles[(__nibblepos)] = nibbles[(__nibblepos)] | (1 << (__bitpos))
    #define DM_CLR_BIT(__nibblepos, __bitpos) nibbles[(__nibblepos)] = nibbles[(__nibblepos)] & (~(1 << (__bitpos)))
        
    while(1)
    {
        /* matrix scan the keyboard */
        nibble_cnt = 0;
        bit_cnt = 0;
        for (col = 0; col < Size_ColMapping_C65; col++)
        {
            /* set all columns to LOW except the currently active one */
            for (i = 0; i < Size_ColMapping_C65; i++)
            {
                TM_GPIO_SetPinValue(Columns_C65[i].GPIOx, Columns_C65[i].GPIO_Pin, (i == col) ? 1 : 0);
                if (i < Size_ColMapping_C64)
                    TM_GPIO_SetPinValue(Columns_C64[i].GPIOx, Columns_C64[i].GPIO_Pin, (i == col) ? 1 : 0);                    
            }
                     
            /* perform standard row scanning as the MEGA65 can handle that in an untranslated (raw) way
               deliberately only scan rows 0..7 as row 8 is only for CAPS LOCK (ASCII/DIN), which needs a special treatment 
               plus: this way of doing it elegantly enables us to scan the C64 rows in parallel */            
            for (row = 0; row < 8; row++)
            {
                /* Commodore 65 */
                if (TM_GPIO_GetInputPinValue(Rows_C65[row].GPIOx, Rows_C65[row].GPIO_Pin) == 1)                    
                {
                    /* a key is pressed, so set the corresponding matrix bit */
                    DM_SET_BIT(nibble_cnt, bit_cnt);
                  	TM_SWO_Printf("C65 Key: col=%i, row=%i, nibble=%i, bit=%i.\n", col, row, nibble_cnt, bit_cnt);
                }
                
                /* Commodore 64 */
                else if (col < Size_ColMapping_C64 ? TM_GPIO_GetInputPinValue(Rows_C64[row].GPIOx, Rows_C64[row].GPIO_Pin) == 1 : 0)
                {    
                    /* detect the C64 mode */
                    if (!C64_Mode)
                    {
                        C64_Mode = 1;
                        TM_SWO_Printf("C64 mode detected. Swapping joystick ports back to normal.\n");
                        
                        for (i = 0; i < Size_JoyMapping / 2; i++)
                        {
                            tmp_offs = (Size_JoyMapping / 2) + i;
                            tmp_nbl = Joystick[i].nibble_count;
                            tmp_bit = Joystick[i].bit_count;
                            Joystick[i].nibble_count = Joystick[tmp_offs].nibble_count;
                            Joystick[i].bit_count = Joystick[tmp_offs].bit_count;
                            Joystick[tmp_offs].nibble_count = tmp_nbl;
                            Joystick[tmp_offs].bit_count = tmp_bit;
                        }
                    }
                    
                    /* a key is pressed, so set the corresponding matrix bit */
                    DM_SET_BIT(nibble_cnt, bit_cnt);
                  	TM_SWO_Printf("C64 Key: col=%i, row=%i, nibble=%i, bit=%i.\n", col, row, nibble_cnt, bit_cnt);                    
                }
                
                /* key is released, so clear the corresponding matrix bit */
                else
                    DM_CLR_BIT(nibble_cnt, bit_cnt);
                
                bit_cnt++;
                
                if (bit_cnt == 4)
                {
                    bit_cnt = 0;
                    nibble_cnt++;
                }

                Delay(1);
            }            
        }
        
        /* C65 only: handle CURSOR UP and CURSOR LEFT: to be emulated as SHIFT+CURSOR DOWN and SHIFT+CURSOR RIGHT */
        for (i = 0; i < 8; i++)
            TM_GPIO_SetPinValue(Columns_C65[i].GPIOx, Columns_C65[i].GPIO_Pin, (i == COL_CSR) ? 1 : 0);                
        if (TM_GPIO_GetInputPinValue(Rows_C65[ROW_CSR_UP].GPIOx, Rows_C65[ROW_CSR_UP].GPIO_Pin) == 1)
        {
            /* CURSOR UP */
            DM_SET_BIT(NIBBLE_CSR_DOWN, BIT_CSR_DOWN);
            DM_SET_BIT(NIBBLE_RIGHT_SHIFT, BIT_RIGHT_SHIFT);
        }
        Delay(1);
        if (TM_GPIO_GetInputPinValue(Rows_C65[ROW_CSR_LEFT].GPIOx, Rows_C65[ROW_CSR_LEFT].GPIO_Pin) == 1)
        {
            /* CURSOR LEFT */
            DM_SET_BIT(NIBBLE_CSR_RIGHT, BIT_CSR_RIGHT);
            DM_SET_BIT(NIBBLE_RIGHT_SHIFT, BIT_RIGHT_SHIFT);            
        }
        Delay(1);
        
        /* handle RESTORE key (inverse logic) */
        if ((TM_GPIO_GetInputPinValue(Restore_C65.GPIOx, Restore_C65.GPIO_Pin) == 0) ||
            (TM_GPIO_GetInputPinValue(Restore_C64.GPIOx, Restore_C64.GPIO_Pin) == 0))
            DM_SET_BIT(NIBBLE_RESTORE, BIT_RESTORE);
        else
            DM_CLR_BIT(NIBBLE_RESTORE, BIT_RESTORE);
        Delay(1);
        
        /* C65 only: handle CAPS LOCK (aka ASCII/DIN) (inverse logic) */
        if (TM_GPIO_GetInputPinValue(Rows_C65[ROW_CAPSLOCK].GPIOx, Rows_C65[ROW_CAPSLOCK].GPIO_Pin) == 0)
            DM_SET_BIT(NIBBLE_CAPSLOCK, BIT_CAPSLOCK);
        else
            DM_CLR_BIT(NIBBLE_CAPSLOCK, BIT_CAPSLOCK);
        Delay(1);
        
        /* handle joysticks */
        for (i = 0; i < Size_JoyMapping; i++)
        {
            if (TM_GPIO_GetInputPinValue(Joystick[i].GPIOx, Joystick[i].GPIO_Pin) == 0)
            {
                DM_SET_BIT(Joystick[i].nibble_count, Joystick[i].bit_count);
              	TM_SWO_Printf("Joystick: i=%i, nibble=%i, bit=%i.\n", i, Joystick[i].nibble_count, Joystick[i].bit_count);
            }
            else
                DM_CLR_BIT(Joystick[i].nibble_count, Joystick[i].bit_count);
            Delay(1);
        }
        
        /* handle the LEDs */
        TM_GPIO_SetPinValue(LEDs[ledPower].GPIOx, LEDs[ledPower].GPIO_Pin, FPGA_IN_PowerLed ? 0 : 1);
        TM_GPIO_SetPinValue(LEDs[ledFDD].GPIOx, LEDs[ledFDD].GPIO_Pin, FPGA_IN_FDDLed ? 0 : 1);
        Delay(1);
                
        /* transmit current keyboard and joystick state to FPGA and read the LED status from the FPGA */
        for (i = 0; i < 32; i++)
        {
            FPGA_OUT(P_CLOCK, 0);                                   /* clock = 0 while data is being assembled */            
            FPGA_OUT(P_START, (i == 0) ? 1 : 0);                    /* start of sequence = 1 at the very first nibble */
            
            FPGA_OUT(P_OUT_B0, (nibbles[i] & 0x01) ? 0 : 1);        /* set data lines and use inverse logic */
            FPGA_OUT(P_OUT_B1, (nibbles[i] & 0x02) ? 0 : 1);
            FPGA_OUT(P_OUT_B2, (nibbles[i] & 0x04) ? 0 : 1);
            FPGA_OUT(P_OUT_B3, (nibbles[i] & 0x08) ? 0 : 1);
                            
            Delay(1);                                               /* wait for everything to settle ... */            
            FPGA_OUT(P_CLOCK, 1);                                   /* ... then clock = 1 to trigger the FPGA to read */                                    
            Delay(1);                                               /* give the FPGA's flip/flops some time to read the data */
            
            /* read the LED status */
            if (i == 0)
            {
                FPGA_IN_PowerLed = FPGA_IN(P_IN_B0);
                FPGA_IN_FDDLed   = FPGA_IN(P_IN_B1);                
            }            
        }
    }
}

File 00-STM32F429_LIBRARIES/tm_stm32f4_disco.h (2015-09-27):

/**
 * @author  Tilen Majerle
 * @email   tilen@majerle.eu
 * @website http://stm32f4-discovery.com
 * @link    http://stm32f4-discovery.com/2014/04/stm32f429-discovery-gpio-tutorial-with-onboard-leds-and-button/
 * @version v1.11
 * @ide     Keil uVision
 * @license GNU GPL v3
 * @brief   Leds and button library for STM32F401 - , STM32F4 -, STM32F411 - and STM32F429 Discovery boards.
 *          Also works with Nucleo F411 and Nucleo F401 boards and STM324x9-EVAL boards
 *	
@verbatim
   ----------------------------------------------------------------------
    Copyright (C) Tilen Majerle, 2015
    
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
    You should have received a copy of the GNU General Public License
    along with this program.  If not, see <http://www.gnu.org/licenses/>.
   ----------------------------------------------------------------------
@endverbatim
 */
#ifndef TM_DISCO_H
#define TM_DISCO_H 1110
/**
 * @addtogroup TM_STM32F4xx_Libraries
 * @{
 */

/**
 * @defgroup TM_DISCO
 * @brief    Leds and buttons for STM32F4 Discovery, Nucleo and eval boards - http://stm32f4-discovery.com/2014/04/stm32f429-discovery-gpio-tutorial-with-onboard-leds-and-button/
 * @{
 *
 * Library supports all STM32F4 Discovery boards, All STM32F4 Nucleo boards and STM324x9 eval board.
 *	
 * \par Supported boards
 *			
 * - STM32F429 Discovery: (STM32F429ZI) - <code>TM_DISCO_STM32F429_DISCOVERY</code>
 *   - Leds:
 *     - LED_GREEN   on PG13
 *     - LED_RED     on PG14
 *   - Button: (HIGH when pressed)
 *     - Blue button on PA0	
 * - NUCLEO-F401: (STM32F401RE) - <code>TM_DISCO_NUCLEO_F401</code>
 * - NUCLEO-F411: (STM32F411RE) - <code>TM_DISCO_NUCLEO_F411</code>
 *   - Led:
 *     - LED_GREEN   on PA5
 *   - Button: (LOW when pressed)
 *     - Blue button on PC13
 * - STM32F401-Discovery: (STM32F401VC) - <code>TM_DISCO_STM32F401_DISCOVERY</code>
 * - STM32F411-Discovery: (STM32F411VE) - <code>TM_DISCO_STM32F411_DISCOVERY</code>
 * - STM32F4-Discovery: (STM32F407VG) - <code>TM_DISCO_STM32F4_DISCOVERY</code>
 *   - Leds:
 *     - LED_GREEN   on PD12
 *     - LED_ORANGE  on PD13
 *     - LED_RED     on PD14
 *     - LED_BLUE    on PD15
 *   - Button: (HIGH when pressed)
 *     - Blue button on PA0
 * - STM324x9-Eval (STM32F439NI) - <code>TM_DISCO_STM324x9_EVAL</code>
 *   - Leds:
 *     - LED_GREEN   on PG6
 *     - LED_ORANGE  on PG7
 *     - LED_RED     on PG10
 *     - LED_BLUE    on PG12
 *   - Button: (HIGH when pressed)
 *     - Blue button on PA0
 *
 * \par Select your board
 *
 * To select your board, you have several options:
 *   - Add define for your board in defines.h file or
 *   - Add define for your board in compiler's global settings
 *     - For Keil uVision you have "Options for Target" and "C/C++" tab where you can set this.
 *
 * Imagine, we want to work with STM324x9-Eval board. Then, you can open <code>defines.h</code> file and add define:
 *
@verbatim
//Select STM324x9-Eval for DISCO library
#define TM_DISCO_STM324x9_EVAL
@endverbatim
 * Or if you want STM32F429-Discovery, do this:
@verbatim
//Select STM32F429-Discovery for DISCO library
#define TM_DISCO_STM32F429_DISCOVERY
@endverbatim
 *
 * \par Changelog
 *
@verbatim
 Version 1.11
  - March 18, 2015
  - Added support for STM324x9-Eval board
  
 Version 1.10
  - March 14, 2015
  - Fixed issue with pull resistors on boards

 Version 1.9
  - March 10, 2015
  - Added support for my new GPIO library
  - Added support for STM32F411-Discovery board

 Version 1.8
  - February 01, 2015
  - Added support for button OnPress and OnRelease events
 
 Version 1.7
  - December 02, 2014
  - Fixed bug with checking if led is on
 
 Version 1.6
  - November 28, 2014
  - Almost all functions are now defines, for faster execution		
 
 Version 1.5
  - November 06, 2014
  - Added function TM_DISCO_SetLed()
 
 Version 1.4
  - Added support for Nucleo F411-RE board
 
 Version 1.3
  - Added support for STM32F401 Discovery board
 
 Version 1.2
  - Added support for Nucleo F401-RE board
 	
 Version 1.1
  - Check if LED is on or off

 Version 1.0
  - First release
@endverbatim
 *
 * \par Dependencies
 *
@verbatim
 - STM32F4xx
 - defines.h
 - TM GPIO
@endverbatim
 */
#include "stm32f4xx.h"
#include "defines.h"
#include "tm_stm32f4_gpio.h"

/* Recognize correct board */
/* CooCox support */
#if defined(STM32F429_439xx) || defined(STM32F429ZI)
	/* STM32F429 Discovery support */
	#ifndef TM_DISCO_STM32F429_DISCOVERY
		#define TM_DISCO_STM32F429_DISCOVERY
	#endif 
#elif defined(STM32F407VG) || defined(STM32F401VC)// || defined(STM32F40_41xxx)
	/* STM32F4 and STM32F401 Discovery support */
	#ifndef TM_DISCO_STM32F4_DISCOVERY
		#define TM_DISCO_STM32F4_DISCOVERY
	#endif
#elif defined (STM32F401xx) || defined(STM32F401RE) || defined(STM32F401RB)
	/* Nucleo F401RE board support */
	#ifndef TM_DISCO_NUCLEO_F401
		#define TM_DISCO_NUCLEO_F401
	#endif
#elif defined (STM32F411xx) || defined(STM32F411RE) || defined(STM32F411RB)
	/* Nucleo F411RE board support */
	#ifndef TM_DISCO_NUCLEO_F411
		#define TM_DISCO_NUCLEO_F411
	#endif
#endif
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

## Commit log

2015-09-27 Initial commit: Basic keyboard functionality (special keys are still wip)
    [c65Keyb.brd, c65Keyb.sch]
2015-09-27 added firmware binary and how-to-flash instructions
    [dm65pic.cfg]
2015-10-03 added how-to-build-a-cable documentation
2015-10-03 support for C64 standard keyboards and joyport swapping
    [main.c]
2015-10-04 added LED support and updated the eagle schematics
    [c65Keyb.brd, c65Keyb.sch]
2015-10-06 inverted the LED logic
    [main.c]

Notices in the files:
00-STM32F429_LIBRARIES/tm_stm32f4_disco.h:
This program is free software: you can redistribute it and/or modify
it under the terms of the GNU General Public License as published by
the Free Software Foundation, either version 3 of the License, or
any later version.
